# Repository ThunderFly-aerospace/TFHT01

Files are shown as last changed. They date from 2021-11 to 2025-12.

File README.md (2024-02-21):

# TFHT01 - UAV Humidity and Temperature Sensor



The TFHT01 hygrometer sensor offers flexible integration options. It can be directly connected to a Pixhawk autopilot with PX4 firmware, or it can be used as a sensor for the [TF-ATMON monitoring system](https://www.thunderfly.cz/tf-atmon.html).

Sensors mounted on UAVs can be used for a variety of purposes. TFHT01 can measure air temperature and humidity, which can be used for meteorological purposes to estimate whether icing may form on aerodynamic surfaces. It could also be used to determine if the flight is conducted within the operating range of the drone. Another use can be to measure the temperature of selected UAV components, for example, the temperature of batteries, ESC, motor, or some bearings. 

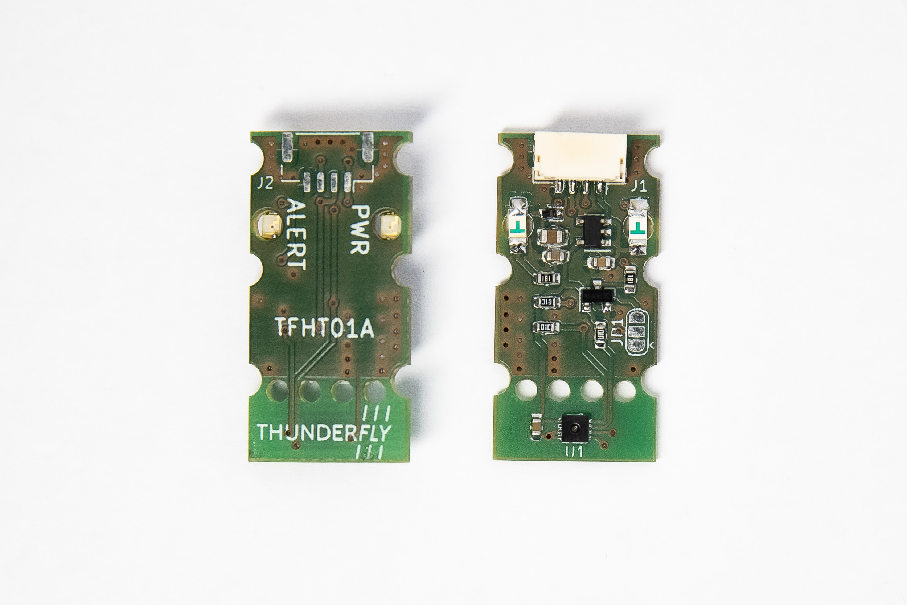
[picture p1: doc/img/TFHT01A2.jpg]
TFHT01A top view


## Where to get it?

The TFHT01 is commercially available from [ThunderFly s.r.o.](https://www.thunderfly.cz/). For a commercial quotation or support, contact us by email at sale@thunderfly.cz or shop at [Tindie store](https://www.tindie.com/products/thunderfly/tfht01-aerial-hygrometer-and-thermometer/).

## Parameters

| Parameter | Value | Description |
|---|---|---|
| Sensing element | [SHT35](https://sensirion.com/media/documents/213E6A3B/63A5A569/Datasheet_SHT3x_DIS.pdf) | Other possible sensors are SHT30 or SHT31 |
| Typical accuracy | 1.5 %RH and 0.1 °C | |
| Repeatability | 0.15 %RH , 0.08 °C | The stated repeatability is 3 times the standard deviation (3σ) of multiple consecutive measurements at constant ambient conditions. |
| Operating temperature range| 0 °C - +65 °C | Sensor physically measures in range -40°C to +120°C with reduced accuracy |
| Operating humidity range| 0-100 % | At humidity above 80% the performance of the sensor could be degraded in case of prolonged periods |
| I2C connector | 4-pin JST-GH | The second connector could be installed on the opposite side |
| I2C address | 0x44 default | By switching of JP1 is possible change address to 0x45 |
| Storage temperature range| -20 °C - +40 °C |  |
| Operational input voltage | 3.6 - 5.4V | Overvoltage internally protected by zener diode |
| Mass | 2 g | PCB without cabling |
| Dimensions | 30 x 15 x 6.5 mm |  PCB |
| Weather resistance | IP40 | External connectors fully occupied. The sensor itself could be protected by IP67 according the [sensirion datasheet](https://sensirion.com/media/documents/9D103E42/61641F0F/Sensirion_Humidity_Sensors_SHT3x_Datasheet_Filter_Membrane.pdf) |

## Applications

### Atmospheric sounding

The TFHT01 sensor could be used for [direct atmospheric sounding](https://en.wikipedia.org/wiki/Atmospheric_sounding). Here is an example of measured data taken by [TF-G2 autogyro](https://www.thunderfly.cz/tf-g2.html).

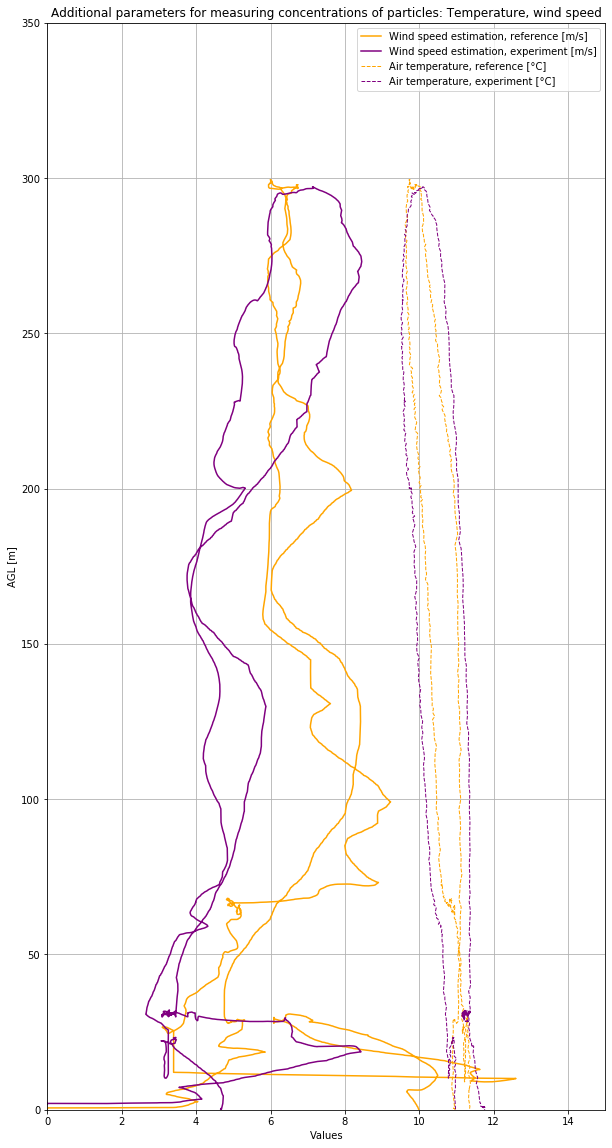
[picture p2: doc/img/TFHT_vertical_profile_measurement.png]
TFHT01A atmospheric profiling


## Schematics

Schematics

## Usage in PX4 autopilot firmware

The PX4 autopilot firmware supports the sensor. Multiple sensors can be connected to one autopilot. The measured data are immediately sent to the ground station and they are also logged in the onboard ulog file. Sensor support can be enabled by setting the [SENS_EN_SHT3X](http://docs.px4.io/master/en/advanced_config/parameter_reference.html#SENS_EN_SHT3X) parameter to 1.

### Driver Commands Examples

CLI usage example:

    sht3x start -X

Start the sensor driver on the external bus

    sht3x status

Print driver status

    sht3x values

Print the last measured values

    sht3x reset

Reinitialize senzor, reset flags

### PX4 Driver Usage

```
sht3x <command> [arguments...]
 Commands:
   start
     [-I]        Internal I2C bus(es)
     [-X]        External I2C bus(es)
     [-b <val>]  board-specific bus (default=all) (external SPI: n-th bus
                 (default=1))
     [-f <val>]  bus frequency in kHz
     [-q]        quiet startup (no message if no device found)
     [-a <val>]  I2C address
                 default: 68
     [-k]        If initialization (probing) fails, keep retrying periodically

   stop

   status        print status info

   values        Print actual data

   reset         Reinitialize sensor
```

## Usage in Ardupilot firmware

In the Ardupilot firmware, the corresponding sht3x driver for TFHT01 is currently missing. The contributions are welcomed. 

## Resources

  * [ThunderFly TFHT01 documentation page](https://docs.thunderfly.cz/avionics/TFHT01/)
  * [Store](https://www.tindie.com/products/26354/)
  * [Contact details](https://www.thunderfly.cz/contact-us.html)

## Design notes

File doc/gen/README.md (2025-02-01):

# PCB

Board size: 30.0x15.0 mm (1.18x0.59 inches)

- This is the size of the rectangle that contains the board
- Thickness: 0.89 mm (35 mils)
- Material: FR4
- Finish: HAL lead-free
- Layers: 2
- Copper thickness: 35 µm

Solder mask: TOP / BOTTOM

- Color: Green

Silk screen: TOP / BOTTOM

- Color: White

Stackup:

| Name | Type | Color | Thickness [µm]| Material | Er | Loss tan |
|---|---|---|---|---|---|---|
| F.SilkS | Top Silk Screen | | | | | |
| F.Mask | Top Solder Mask | Green | 10 | | | |
| F.Cu | copper | | 35 | | | |
| dielectric 1 | core | | 800 | FR4 | 4.5 | 0.020 |
| B.Cu | copper | | 35 | | | |
| B.Mask | Bottom Solder Mask | Green | 10 | | | |
| B.SilkS | Bottom Silk Screen | | | | | |

# Important sizes

Clearance: 0.2 mm (8 mils)

Track width: 0.3 mm (12 mils)

- By design rules: 0.15 mm (6 mils)

Drill: 0.5 mm (20 mils)

- Vias: 0.5 mm (20 mils) [Design: 0.4 mm (16 mils)]
- Pads: 1.0 mm (39 mils)
- The above values are real drill sizes, they add 0.1 mm (4 mils) to plated holes (PTH)

Via: 0.8/0.4 mm (31/16 mils)

- By design rules: 0.4/0.3 mm (16/12 mils)
- Micro via: yes [0.2/0.1 mm (8/4 mils)]
- Buried/blind via: yes
- Total: 36 (thru: 36 buried/blind: 0 micro: 0)

Outer Annular Ring: 0.15 mm (6 mils)

- By design rules: N/A mm (N/A mils)

Eurocircuits class: 4B
- Using min drill 0.5 mm for an OAR of 0.15 mm

# General stats

Components count: (SMD/THT)

- Top: 1/6 (SMD + THT)
- Bottom: 16/1 (SMD + THT)

Defined tracks:

- 0.3 mm (12 mils)
- 0.4 mm (16 mils)
- 0.5 mm (20 mils)
- 1.0 mm (39 mils)

Used tracks:

- 0.3 mm (12 mils) (54) defined: yes
- 0.4 mm (16 mils) (111) defined: yes

Defined vias:

Used vias:

- 0.8/0.4 mm (31/16 mils) (Count: 36, Aspect: 1.1 A) defined: no

Holes (excluding vias):

- 1.0 mm (39 mils) (12)
- 3.0 mm (118 mils) (6)

Oval holes:

Drill tools (including vias and computing adjusts and rounding):

- 0.5 mm (20 mils) (36)
- 1.0 mm (39 mils) (12)
- 3.0 mm (118 mils) (6)

Solder paste stats:

Using a paste with 87.75 % alloy, that has an specific gravity for the alloy of 7.4 g/cm³
and 1.0 g/cm³ for the flux. This paste has an specific gravity of  4.15 g/cm³.

The stencil thickness is  0.12 mm.

| Side | Pads with paste | Area [mm²] | Paste [g] |
|---|---|---|---|
| Top | 6 | 9.28 | 0.05 |
| Bottom | 47 | 40.69 | 0.20 |
| Total  | 53 | 49.97 | 0.25 |

Note: this is just an approximation to the theoretical value. Margins of the solder mask and waste aren't computed.

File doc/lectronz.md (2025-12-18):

The TFHT01 hygrometer sensor offers flexible integration options, including direct connection to a Pixhawk autopilot with PX4 firmware, or utilization as a sensor for the [TF-ATMON monitoring system](https://www.thunderfly.cz/tf-atmon.html). 

Once mounted on a UAV, the sensor provides valuable data for various applications. Its ability to measure atmospheric temperature and humidity can help estimate that icing may form on aerodynamic surfaces or determine if the drone is operating within the recommended range. Furthermore, the sensor can also be utilized to measure the temperature of specific UAV components such as batteries, ESCs, motors, or bearings, identifying potential issues before they escalate and supporting proactive maintenance and repairs.

Choose the TFHT01 hygrometer sensor for unparalleled flexibility, precision, and versatility in data collection. Whether you require temperature and humidity data for agricultural or industrial equipment monitoring or need to monitor drone component temperatures for optimal performance, the TFHT01 has you covered.

### What is it?

TFHT01 is a hygrometer and thermometer with an I2C interface for use on drones as an onboard weather station. Relative humidity and temperature are quantities that can affect both the flight characteristics of the drone and the execution of aerial works. At certain temperatures and relative humidity, icing can form on the lifting surfaces, worsening its flight characteristics or even causing a crash. Meteorological conditions can affect the payload as well - they can cause e.g. fogging on camera lenses, etc. It is therefore important to know about the presence of these phenomena during the flight.

| Parameter | Value | Description |
|---|---|---|
| Sensing element | [SHT35](https://sensirion.com/media/documents/213E6A3B/63A5A569/Datasheet_SHT3x_DIS.pdf) | Other possible sensors SHT30, SHT31 |
| Typical accuracy | 1.5 %RH and 0.1 °C | |
| Repeatability | 0.15 %RH , 0.08 °C | The stated repeatability is 3 times the standard deviation (3σ) of multiple consecutive measurements at constant ambient conditions. |
| Operating temperature range| 0 °C - +65 °C | Sensor physically measures in range -40°C to +120°C with reduced accuracy |
| Operating humidity range| 0-100 % | At humidity above 80% the performance of the sensor could be degraded in case of prolonged periods |
| I2C connector | 4-pin JST-GH | The second connector could be installed on the opposite side |
| I2C address | 0x44 default | By switching of JP1 is possible change address to 0x45 |
| Storage temperature range| -20 °C - +40 °C |  |
| Operational input voltage | 3.6 - 5.4V | Overvoltage internally protected by zener diode |
| Mass | 2 g | PCB without cabling |
| Dimensions | 30 x 15 x 6.5 mm |  PCB |
| Weather resistance | IP40 |  |

### How could be used 
We developed the TFHT01 because we needed to know the temperature and humidity of the environment in which we operate our drones. At that time no such sensor was commercially available on the market.

### Special features
The sensor is unique because it is ready to be immediately used on drones. It complies with the widely used dronecode standards and it is equipped with indicator diodes that help with quick diagnostics of the status of the sensor and its operating status.

Furthermore, the sensor has a specific construction that makes it possible to place it in the outdoor environment easily. Alternatively, the sensor can be used as a diagnostics probe for drone avionics’ (e.g. engines, regulators, or batteries).

### Compatibility with autopilots

Our sensor is fully compatible with the dronecode standards. In terms of software, the sensor is supported by [PX4 autopilot](https://px4.io/). The driver is programmed as a so-called multi-instance. Thanks to this it is possible to connect multiple TFHT01 sensors to the autopilot (they can be located in different parts of the drone or measure data from different drone’s components). This should be done concerning I2C bus properties, e.g. requirement of [different addresses for each device on the bus](https://lectronz.com/products/1063).

### Use with PX4

Complete settings and driver options under PX4 can be found in the [documentation](https://docs.px4.io/main/en/modules/modules_driver.html#sht3x).

To start the driver automatically it is only necessary to connect the sensor to any I2C port and set the `SENS_EN_SHT3x` parameter to 1 (enabled). The sensor should initialize during the next start. The prerequisite is to use the PX4 firmware version newer than 2022/03.

You can check that the driver is running and the sensor is initialized, after turning the driver on, the LED ‘ALERT’ is off.

Data is logged locally in the drone’s onboard avionics and is sent via Mavlink to the ground station. The values can be viewed in real-time using control software e.g. [QGC](http://qgroundcontrol.com/).

### Another usage
The sensor can be used outside of drones and PX4 devices as well. The I2C interface is the 4-pin JST-GH connector. The sensor board also contains I2C pull-ups and that’s why the sensor can be connected to e.g. Arduino or other single-board computers and they can be used to read the data from the sensor. The suggested supply voltage is 5V.

### What’s included?

- 1x TFHT01 with [SHT35 sensor with PTFE membrane](https://sensirion.com/media/documents/9D103E42/61641F0F/Sensirion_Humidity_Sensors_SHT3x_Datasheet_Filter_Membrane.pdf)
- Optionally 1x JST-GH 4-pin I2C cable in accordance to [cable style](https://docs.px4.io/main/en/assembly/cable_wiring.html#i2c-cables)

# Product changelog
The product is gradually evolving and improving based on user requirements. Currently (as of 11/2024), the TFHT01B revision is being shipped. In the development process, we keep backward compatibility, for example by keeping the same form factor or communication interface. The complete list of changes is in [releases](https://github.com/ThunderFly-aerospace/TFHT01/releases).

#### TFHT01B (from 11/2024)
Introduced the use of membrane-covered sensors, and 3D printed sensor housing to enhance environmental protection.

#### TFHT01B (from 10/2023)
PCBs are covered by shrink tubing to increase protection. 

#### TFHT01B (from 05/2022)
PCB Thickness decreased to 0.8mm. 

#### TFHT01A (from 09/2021)
Bare PCB version with 1.6mm thickness

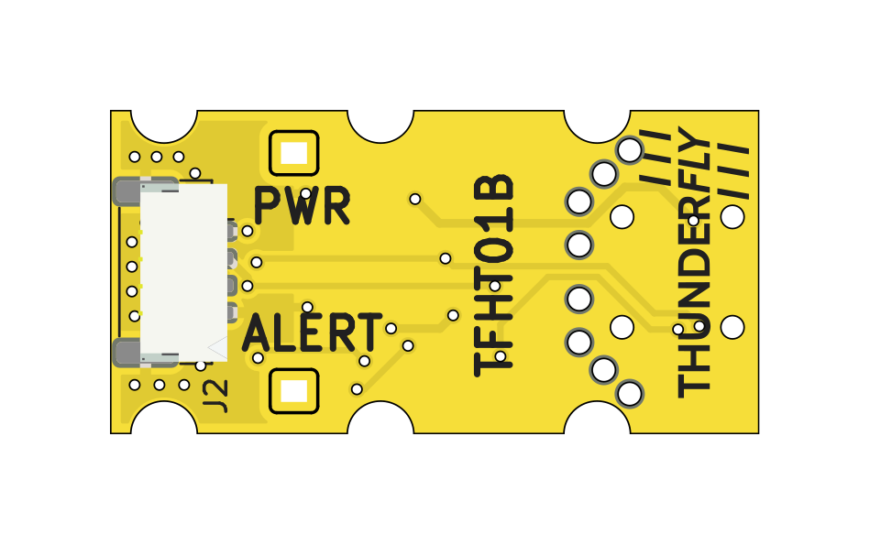
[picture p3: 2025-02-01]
doc/gen/img/TFHT01-top.png

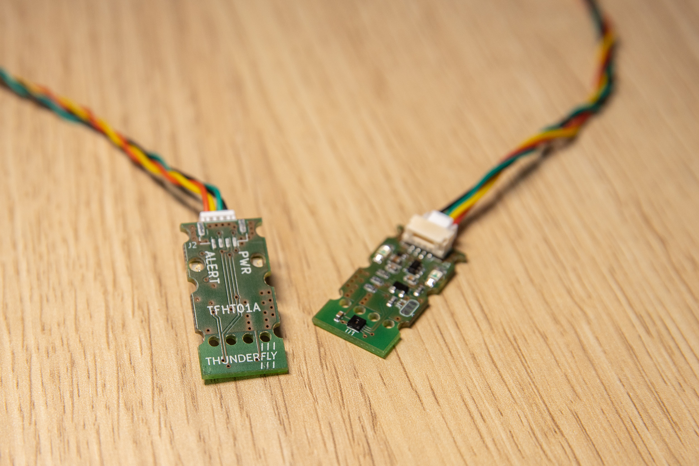
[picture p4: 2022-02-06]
doc/img/TFHT01A1.jpg

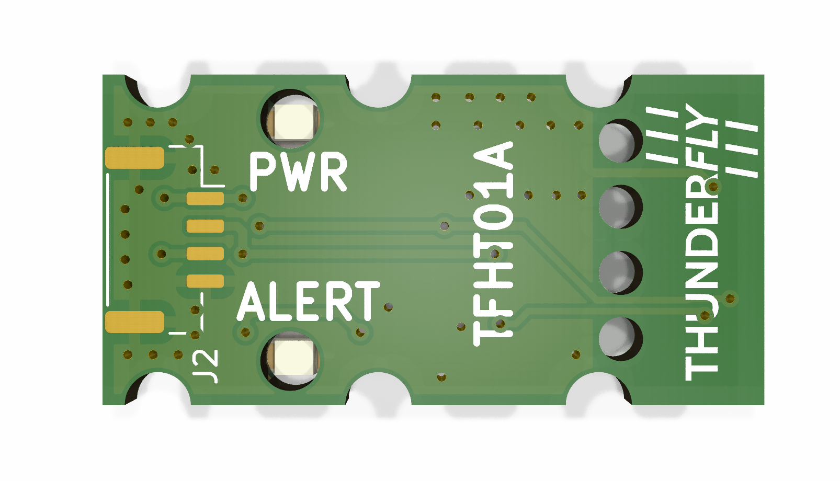
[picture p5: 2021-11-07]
doc/img/TFHT01A_top.png

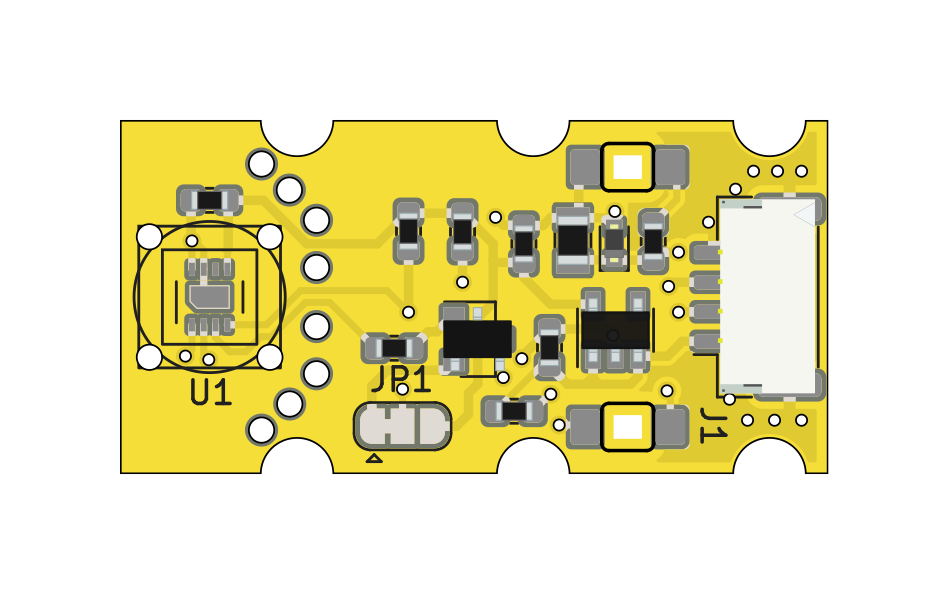
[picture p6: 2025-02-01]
doc/gen/img/TFHT01-bottom.png

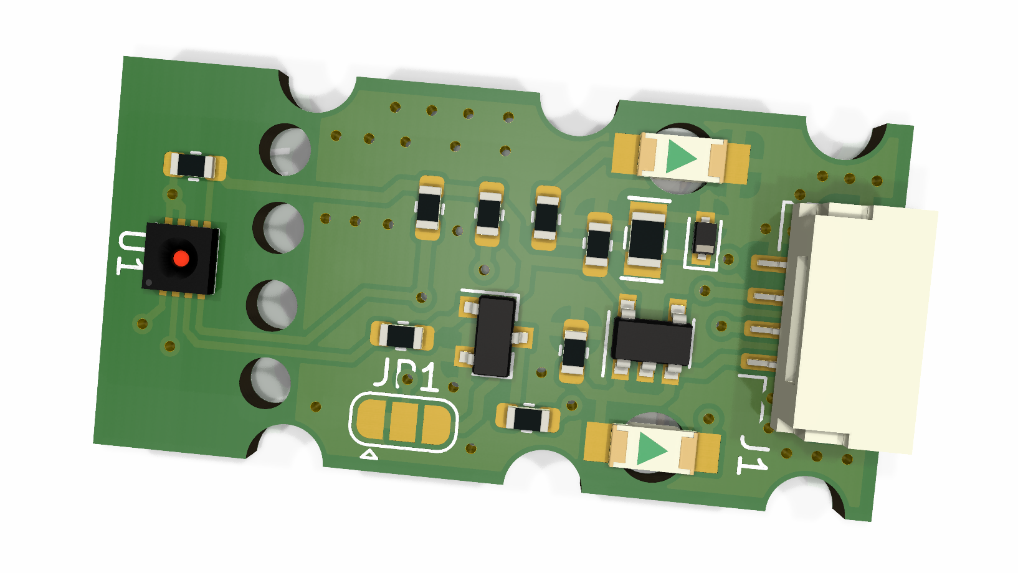
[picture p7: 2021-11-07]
doc/img/TFHT01A_bot.png

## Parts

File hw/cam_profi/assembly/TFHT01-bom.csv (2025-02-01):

Component | Description | Part | References | Value | Footprint | Quantity Per PCB | Datasheet | ust_id
1 | Unpolarized capacitor | C | C4C5 | 100nF | SMD-0603 | 2 | ~ | 5c70984812875079b91f8bf2
2 | Unpolarized capacitor | C | C1 | 1uF | SMD-0603 | 1 | ~ | 5c70984812875079b91f8bc2
3 | Unpolarized capacitor | C | C3 | 10uF | SMD-0805 | 1 | ~ | 5c70984812875079b91f8bbd
4 |  | D_ZENER | D1 | BZX585-B5V6.115 | D_SOD-523 | 1 |  | 60879d38128750769ee58e48
5 | Light emitting diode | LED | D2 | LED GREEN | LED_1206_mill | 1 | ~ | 5c70984412875079b91f8895
6 | Light emitting diode | LED | D3 | LED RED | LED_1206_mill | 1 | ~ | 5c70984412875079b91f8896
7 |  | SM04B-GHS-TB | J1J2 | SM04B-GHS-TB | JST_GH_SM04B-GHS-TB_1x04-1MP_P1.25mm_Horizontal | 2 |  | 5c86273d1287500b4e0280be
8 |  | CAP-SF2 | M7 | CAP-SF2 | CAP-SF2 | 1
9 | 0.8A Ic, 45V Vce, NPN Transistor, SOT-23 | BC817 | Q1 | BC817 | SOT-23 | 1 | http://www.fairchildsemi.com/ds/BC/BC817.pdf | 5c70984712875079b91f8aec
10 | Resistor | R | R1R4 | 180R | SMD-0603 | 2 | ~ | 5c70984512875079b91f8957
11 | Resistor | R | R2R3R10 | 10k | SMD-0603 | 3 | ~ | 5c70984512875079b91f8962
12 | 300mA Low-dropout Voltage Regulator, Vout 3.3V, Vin up to 5.5V, SOT-23 | MIC5504-3.3YM5 | U3 | MIC5504-3.3YM5 | SOT-23-5 | 1 | http://ww1.microchip.com/downloads/en/DeviceDoc/MIC550X.pdf | 5c7255e81287500b4e112ea2
13 | I²C humidity and temperature sensor, ±1.5%RH, ±0.2°C, AEQ-100, DFN-8 | SHT35A-DIS | U1 | SHT35A-DIS | Sensirion_DFN-8-1EP_2.5x2.5mm_P0.5mm_EP1.1x1.7mm | 1 | https://www.sensirion.com/fileadmin/user_upload/customers/sensirion/Dokumente/2_Humidity_Sensors/Datasheets/Sensirion_Humidity_Sensors_SHT3xA_Datasheet.pdf | 65103c42462c6d9e72054b8e

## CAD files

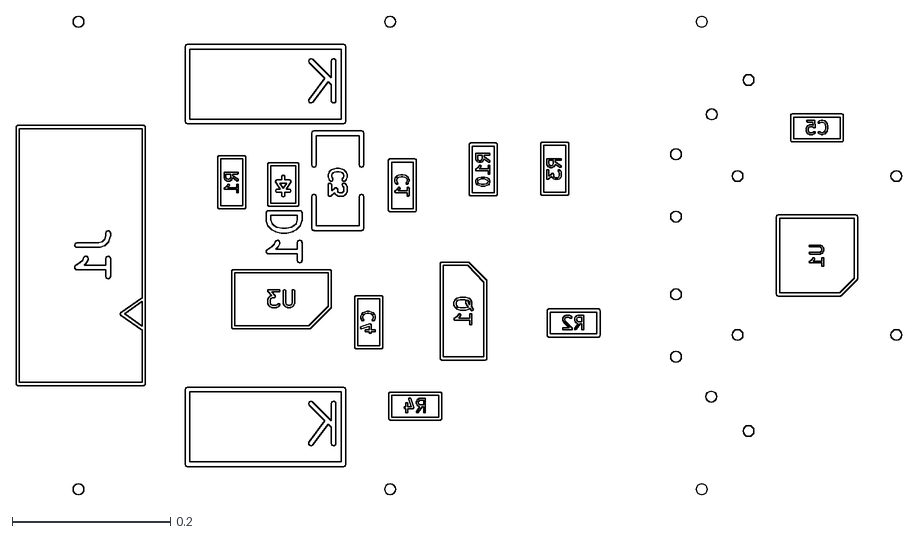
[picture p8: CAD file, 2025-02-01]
doc/gen/dxf/TFHT01-B_Fab.dxf
1.12 x 0.604

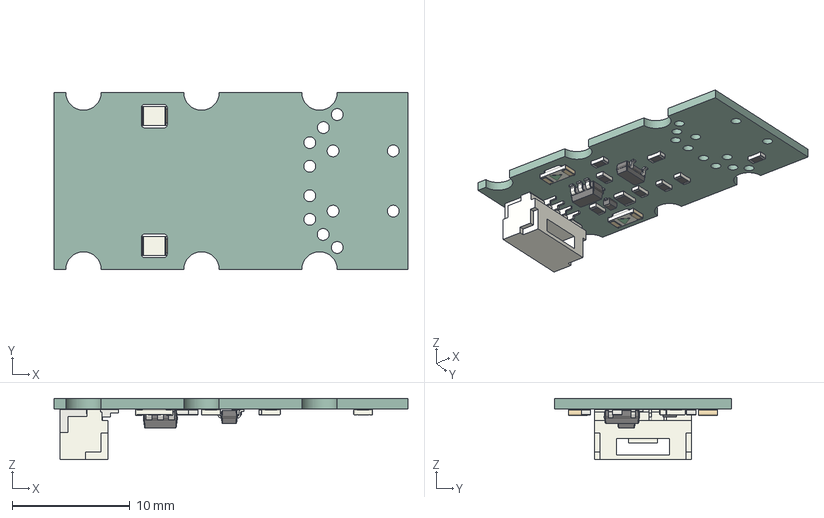
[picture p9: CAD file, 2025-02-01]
doc/gen/TFHT01.step
30.0 x 15.0 x 5.18 mm
LED_1206_3216Metric x 2
R_0603_1608Metric x 8
D_SOD_523
JST_SM04B_GHS_TB
SOT_23
R_0805_2012Metric
SOT_23_5
kibot_k8tr6jyj_PCB

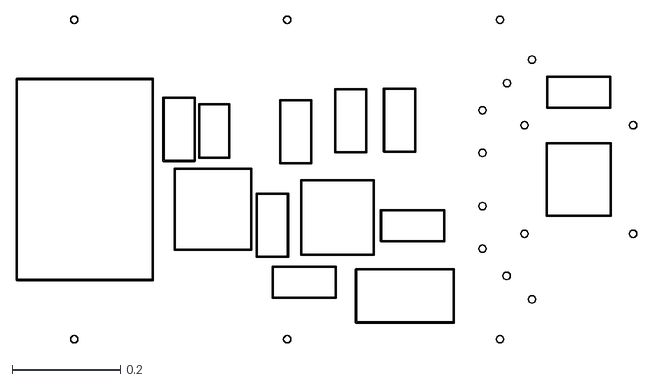
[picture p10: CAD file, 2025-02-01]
doc/gen/dxf/TFHT01-B_Courtyard.dxf
1.15 x 0.604

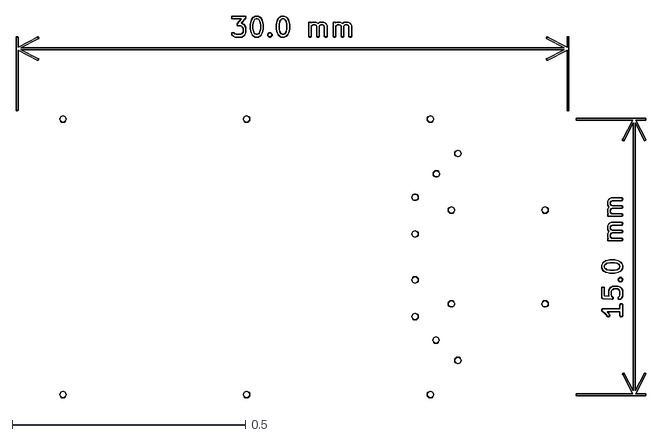
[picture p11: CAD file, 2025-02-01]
doc/gen/dxf/TFHT01-User_Drawings.dxf
1.35 x 0.818

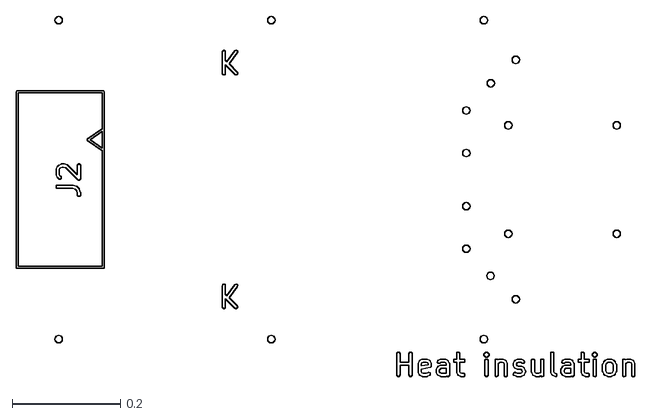
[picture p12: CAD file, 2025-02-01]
doc/gen/dxf/TFHT01-F_Fab.dxf
1.15 x 0.667

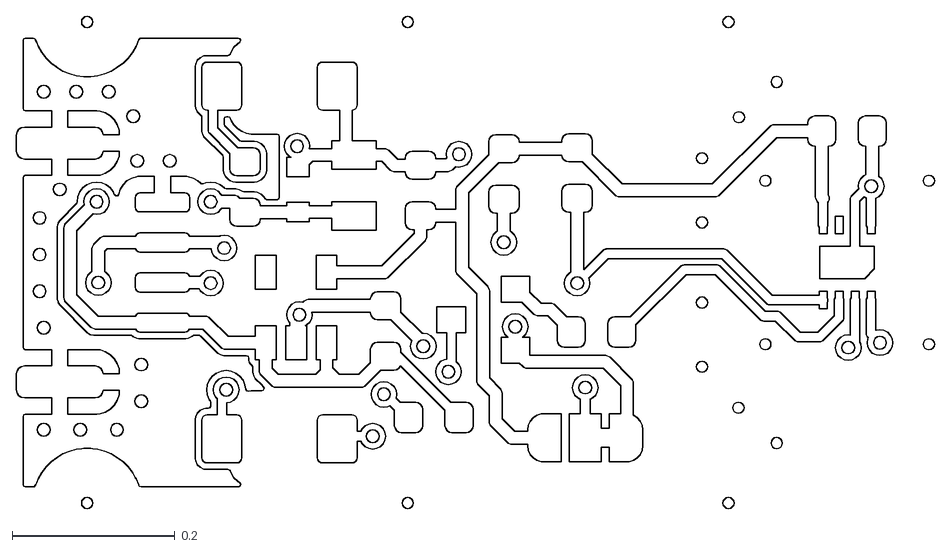
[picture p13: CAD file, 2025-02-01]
doc/gen/dxf/TFHT01-B_Cu.dxf
1.13 x 0.604

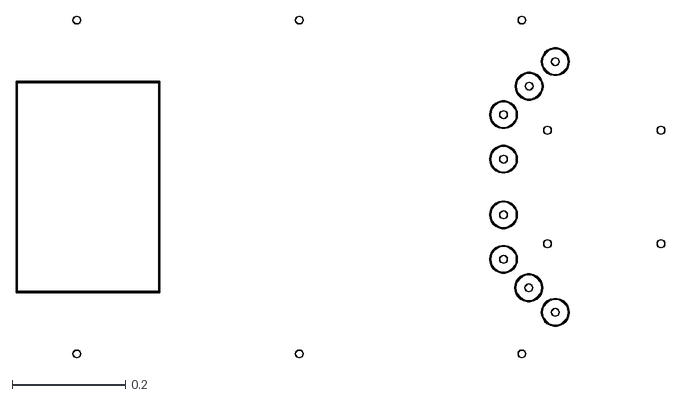
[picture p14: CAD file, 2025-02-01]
doc/gen/dxf/TFHT01-F_Courtyard.dxf
1.15 x 0.604

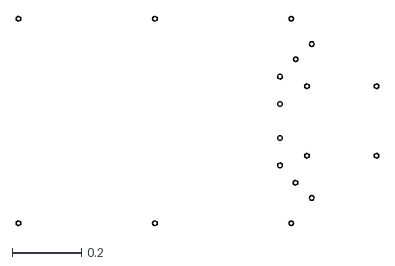
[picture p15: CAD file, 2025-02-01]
doc/gen/dxf/TFHT01-Margin.dxf
1.05 x 0.604

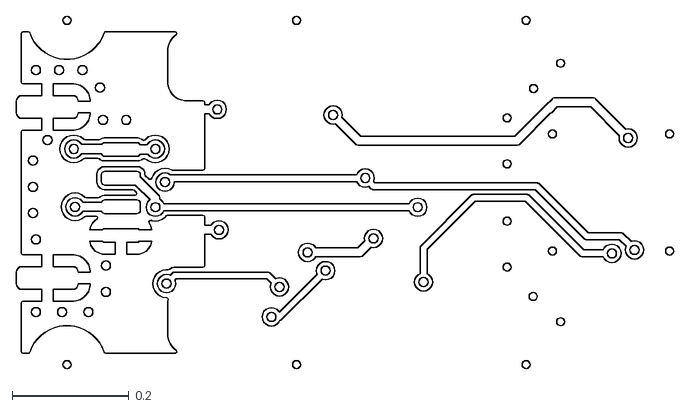
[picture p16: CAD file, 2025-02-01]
doc/gen/dxf/TFHT01-F_Cu.dxf
1.13 x 0.604

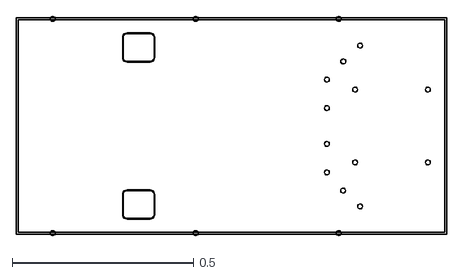
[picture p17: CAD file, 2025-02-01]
doc/gen/dxf/TFHT01-Edge_Cuts.dxf
1.19 x 0.604

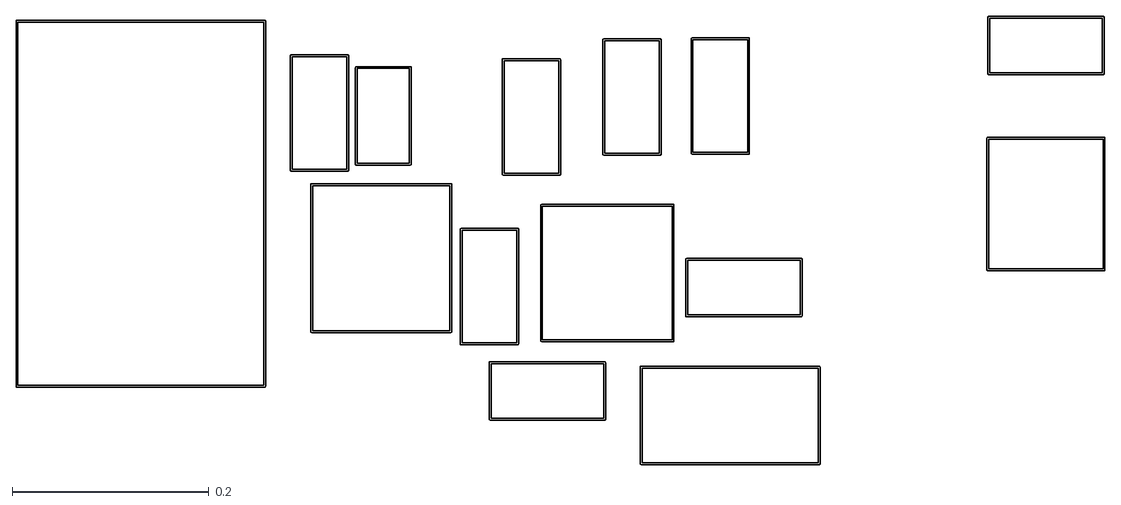
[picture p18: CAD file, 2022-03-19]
doc/gen/dxf/TFHT01B-B_Courtyard.dxf
1.11 x 0.456

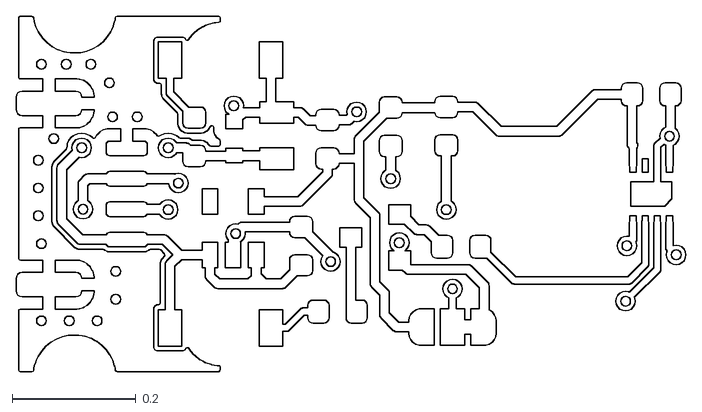
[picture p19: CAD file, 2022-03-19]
doc/gen/dxf/TFHT01B-B_Cu.dxf
1.08 x 0.575

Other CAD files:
doc/gen/dxf/TFHT01-B_Mask.dxf
doc/gen/dxf/TFHT01-B_Paste.dxf
doc/gen/dxf/TFHT01-B_Silkscreen.dxf
doc/gen/dxf/TFHT01-F_Mask.dxf
doc/gen/dxf/TFHT01-F_Paste.dxf
doc/gen/dxf/TFHT01-F_Silkscreen.dxf
doc/gen/dxf/TFHT01B-B_Mask.dxf
doc/gen/dxf/TFHT01B-B_Silkscreen.dxf
doc/gen/dxf/TFHT01B-F_Silkscreen.dxf

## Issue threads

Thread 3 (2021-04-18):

LED label

ChroustJan, 2021-04-18:
@kaklik jaký by měl být text popisků LED?

roman-dvorak, 2021-04-18:
navrhuji:
* PWR
* ALERT

kaklik, 2021-04-18:
Jo Romanův návrh PWR je lepší než můj návrh ON, zde. https://github.com/ThunderFly-aerospace/TFI2CEXT01/issues/4#issuecomment-821993203. Navrhuju to sjednotit na PWR.

ChroustJan, 2021-04-23:
Finální popisek:
PWR
ALERT

Closed 2021-04-23.

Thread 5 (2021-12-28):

Sensor membrane

kaklik, 2021-12-28:
Na další snímače by to chtělo osadit variantu senzorů s [krycím filtrem](https://www.sensirion.com/fileadmin/user_upload/customers/sensirion/Dokumente/2_Humidity_Sensors/Datasheets/Sensirion_Humidity_Sensors_SHT3x_Datasheet_Filter_Membran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), který by měl zabránit znečištění senzoru ve venkovním prostředí.

roman-dvorak, 2022-01-04:
Na telefonu 4. 1. 2022 bylo dohodnuto, že se upraví PCB tak, aby podporoval montáž čepičky [CAP-SF2](https://www.sensirion.com/en/environmental-sensors/humidity-sensors/filter-cap-sf2/), knerá má být schopná zvýšit odolnost senzoru na IP57 (mělo by to být možné ponořit do vody).

Pod čepičku se bude standartně osazovat SHT31.
Jestli to bude varianta s kaptonovou páskou, tak to je na Honzovi. Tak, aby nemohlo při osazování (resp. mytí) dojít k poškození senzoru.

kaklik, 2022-03-12:
Možná že by bylo docela dobré, kdyby TFHT01 bylo vyrobeno na tenčím FR4.  Jednak by se tím ušetřila nějaká hmotnost a potom by filtrační čepička lépe pasovala do otvorů.

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

kaklik, 2022-03-12:
Jsem to překreslil

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

ChroustJan, 2023-08-04:
PCB bude mít 0,8mm

kaklik, 2024-03-17:
Lepší by bylo nahradit čepičku vhodně konstruovanou krabičkou. #10

Closed 2024-03-17.

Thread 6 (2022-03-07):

TFHT01 QGCS configuration

Murali-IsPagro, 2022-03-07:
I am need to measure temperature at 4 different points. how to configure in QGCS if i am connecting the sensor in pixhawk ? Any link for configuration details or setup details?

roman-dvorak, 2022-03-07:
Hello, multiple TFHT01 sensors can be connected to an autopilot with PX4 firmware. The firmware produces a multi-instance uORB message and logs it.

Two sensors can be connected to one bus (with changed address). If you need to connect more sensors, this can be solved by our I2C address translator [TFI2CADT01](https://github.com/ThunderFly-aerospace/TFI2CADT01). We can offer it as a complete solution.

The message is also sent to MAVLINK network. It can be displayed in the QGC [Mavlink inspector](https://docs.qgroundcontrol.com/master/en/analyze_view/mavlink_inspector.html) tool.

What type of autopilot you want to use? Sensor support can be enabled by setting the `[SENS_EN_SHT3X](http://docs.px4.io/master/en/advanced_config/parameter_reference.html#SENS_EN_SHT3X)` parameter to 1.

Murali-IsPagro, 2022-03-08:
I will be using px4 firmware, Pixhawk 2.4.8. You gave me an answer . "Sensor support can be enabled by setting the [SENS_EN_SHT3X](http://docs.px4.io/master/en/advanced_config/parameter_reference.html#SENS_EN_SHT3X) parameter to 1." This is what i was looking for.

Thank you

Closed 2022-03-08.

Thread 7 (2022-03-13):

Nadměrné zahřívání senzoru

roman-dvorak, 2022-03-13:
U dvou TFHT01 senzorů bylo pozorované nadměrné zahřívání.

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

V datasheetu je tato poznámka. Senzor nebyl při měření plně zinicializovaný (neměl vyresetovaný alert registr) a díky tomu mu svítila ALERT LEDka.
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

Podle schéma je tam osazený pouze 100R odpor
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

Což znamená, že senzor je mnohonásobně proudově přetěžován. Opakoavaně jsem kontroloval, že interní vyhřívání senzoru je vypnuté.

Pocitově se ale nejvíce zahřívá střed PCB, kde je umístěný tranzistor a LDO (které díky tomuto incidentu jsou také zbytečně moc vytěžované)

Již při předchozích měření na vírníku bylo pozorováno, že TFHT má o něco vyšší teplotu než teploměr v airspeed senzoru (i když byly jen kus od sebe). Bylo to o jednotky C a nebyla tomu věnována pozornost.

kaklik, 2022-03-13:
Přepočítal jsem parametry toho zapojení.  A za předpokladu, že je tam osazena [tato červená LED](https://www.tme.eu/Document/f2476645d882a001b970b9780aa7dc45/FYLS-1206URC.pdf). Tak současné zapojení umožňuje (5,4-2.1)/180=0,018 A.  Použitý [tranzistor BC817](https://assets.nexperia.com/documents/data-sheet/BC817_SER.pdf), má zesílení minimálně 100.  Tudíž proud do báze musí být v nejhorším případě 100x menší.  To je 0,18 mA.    Při úbytku BE 0,5V by takový proud odpovídal rezistoru v bázi tranzistoru 15k2.  Taková hodnota rezistoru ale není v zapojení nikde použita.
Proto dává větší smysl použít existující hodnotu rezistoru 10k.  Proud do báze tak sice bude mírně vyšší (0,28mA) ale stále řádově menší než současných 28mA.

Ve verzi TFHT01B jsem hodnotu rezistoru opravil.

roman-dvorak, 2022-03-14:
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

Vypnutí LEDky opravdu toto sebezahřívání dost zmenšilo. I tak ale senzor měří o dost (cca 3C) vyšší teplotu než SEN54. Je to vidět na grafu. Všechny senzory jsou umístěné vedle sebe. A i přes nějaké teplotní změny (větrání v pokoji) je jejich offset konstantní. Je to velmi podobná situace jako na vírníku. Viz následující graf:

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
Zde je ale rozdíl, že senzor byl ochlazován a temperován docela velkým množstvím vzduchu protékajícím okolo.

Měření bylo provedeno s nejmenší možnou měřící frekvencí kontinuelního měření (tj. 0.5 Hz). Aby nedocházlo k sebezahřívání z tohoto důvodu.

roman-dvorak, 2022-03-17:
HYGRO01 - TFHT01A v původním osazení z první várky
HYGRO02 - TFDH01A s opravenou hodnotou odporu pro ALERT Ledku (ALERT ledka je zhasnutá)

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

HYGRO02 je včera osazený TFHT. V cca 9h (peak v grafu, ohřátý po pájení) jsem z něj odpájel LEDku. Modrý graf (HYGRO01) má LEDku power stále zapnutou. Je vidět, že po odpájení LEDky poklesla teplota na hodnotu měřenou v SEN54 senzoru.

Vypadá to, že 50mW vytvořené odporem před ledkou a ledkou samotnou zahřívá celý senzor o cca 2C. Senzor je umístěn venku, kde je okolo něj přirozené proudění vzduchu.

kaklik, 2022-03-17:
Navrhuju udělat dvě změny:

1. Snížit proud skrz LED indikující napájení použitím většího odporu
2. Udělat revizi PCB, která nebude obsahovat vylitou měď. Tím pádem bude omezen přenos tepla k senzoru.

kaklik, 2022-03-19:
Ještě jsem rezistor od LED nyní v revizi B přesunul blíže JST-GH konektoru, čímž se dostal dále od snímače.

kaklik, 2023-06-21:
Dalšího zlepšení lze zřejmě dosáhnout odebráním vylité mědi, aby byla snížena tepelná vodivost od rezistorů směrem ke snímači.

kaklik, 2023-07-30:
Zde je situace dobře viditelná na FIR snímku. Snímač, který je výše  má odpojenou LED indikující napájení. LED ALERT svítila jen chvíli, než se senzor inicializoval.
Na snímku je kromě jiného vidět i účinnost vrtaných otvorů.

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

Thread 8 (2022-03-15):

LED type

ChroustJan, 2022-03-15:
Ve verzi 01B bych navrhoval předělat LED do pouzdra 0603. Ty jsme nově začali používat u nových modulů. Potisk na PCB bude z obou stran.

kaklik, 2022-03-15:
Já myslím, že takové rozhodnutí hodně závisí na základním mechanickém uspořádání, které bude použité pro montáž na UAV.
 Reverzní montáž LED bych úplně univerzálně u TF modulů nerušil. Jen to u některých nedává tolik smysl.  (Původní plán uvažoval zejména s využitím pro čidla)

ChroustJan, 2022-03-15:
To neumím rozhodnout. Reverzní montáž je složitější. To vím.

kaklik, 2022-03-19:
> To neumím rozhodnout. Reverzní montáž je složitější. To vím.

V čem je reverzní montáž složitější, když se použijí LED pro reverzní montáž určené?

Já tady ve zrušení té reverzní montáže.  (a obecně u čidel) nevidím velký smysl.  Podle mě je v případě předpokládané montáže senzoru #10  dokonce výhodné, aby LED svítila hlavně na opačnou stranu než je čidlo.  Citlivá část čidla pak může být otočena směrem dolů a tím se v čidle nebude držet voda ani prach. Naopak LED budou z vrchní i spodní strany pravděpodobně snadno viditelné.

ChroustJan, 2022-03-21:
Je potřeba tedy vyřešit správnost footprint. Kvůli DRC se posunuli plošky. Je tedy potřeba přidávat větší množství pasty a někdy i ruční oprava. Dochází k přitažení LED k jedné straně a na druhé straně není kontakt vůbec.

kaklik, 2022-03-21:
Myslím že je chyba řešit chybovou hlášku DRC úpravou footprintu, pokud úprava způsobí technologické potíže.  (Smysl DRC je přesně opačný).
Navíc chybovou hlášku DRC je možné skrýt, čímž přestane generovat neprůchodný výsledek testu.

ChroustJan, 2022-03-21:
Navrhuji vyzkoušet pouzdro, které dal @roman-dvorak  do TFRPM01D. Zavádí příplatkové vnitřní frézování, ale mělo by to řešit problém s osazováním. Nevím zda @roman-dvorak  kontrolovat zda se do díry LED opravdu vejde.

ChroustJan, 2023-02-15:
Romanova změna nebyla dobrá. Udělal jsem jinou. Aktuálně se problém při osazování snížil na minimum.

kaklik, 2023-02-15:
> Romanova změna nebyla dobrá. Udělal jsem jinou. Aktuálně se problém při osazování snížil na minimum.

A skutečně to zavádí nějaký příplatek za vnitřní frézování, nebo to stojí stejně?

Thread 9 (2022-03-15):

Distance of conductive paths from drilled holes

ChroustJan, 2022-03-15:
Je potřeba si ohlídat vzdálenost vodivých cest od vrtaných otvorů. Přijdou mi dost blízko (cca 0,1mm):
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

Snažil jsem se najít nějakou informaci u výrobce, ale nenašel jsem. Jediné co tam mají je vzdálenost mědi od frézování a ta je definovaná jako 0,15mm. Tak bych považoval za rozumné nastavit aspoň tu. Ideálně klidně i větší.

kaklik, 2022-03-15:
Ok, opravíš to, nebo nastavíš to prosím rovnou v tom projektu?

Je tam ještě obdobný problém.. vzdálenosti děr pro CAP-SF2 o okrajů desky. To taktéž nevím zda je nyní správně.

kaklik, 2022-03-15:
> Pokud na tom budu pracovat tak to opravím.
>
> CAP-SF2 je takto špatně. Hrozí že tam bude drážkování a tam je dobré dodržet minimálně 0,5mm vzdálenost mědi od okraje a pak ještě rezervu, aby se to nevylamovalo.

CAP-SF2 ale žádnou měď nepoužívá.

ChroustJan, 2022-03-15:
Těch 0,5mm jsem myslel ve smyslu ochranného pásma pro drážkování. Navrhoval bych jako minimum pro vrtanou díru aspoň 2,5mm. Spíš možná i 3,5mm. Je potřeba brát ohled na nožičky CAP-SF2, že za něco musí držet:
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

kaklik, 2022-03-18:
> Těch 0,5mm jsem myslel ve smyslu ochranného pásma pro drážkování. Navrhoval bych jako minimum pro vrtanou díru aspoň 2,5mm. Spíš možná i 3,5mm. Je potřeba brát ohled na nožičky CAP-SF2, že za něco musí držet: 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

Aby tyhle packy měly ten smysl ke kterému jsou zamýšlené, tak by to PCB muselo mít přibližně poloviční tloušťku.

roman-dvorak, 2022-03-18:
A nešlo by mít pro packy z druhé strany vyvrtané zahloubení? Obdoba zahloubení pro válcovou hlavu šroubu (viz obrázek) Netuším, jak se to definuje ve výrobních datech, ale to by snad mělo jít domluvit s výrobcem.

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

Ale je fakt, že tenčí PCB bude mít menší tepelnou kapacitu, což je u tohoto senzoru docela žádoucí.

kaklik, 2022-03-19:
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

Tohle sice domluvit jde. (Dělá se to tak, že se pošle další vrstva z druhý strany, kde to má být s textovým popisem toho, jak to má být hluboko). Nicméně to bude téměř jistě za příplatek.
Raději bych tady byl pro variantu tenčího PCB, protože to má myslím smysl jak v ušetření hmotnosti, tak i v menší tepelné kapacitě.    Úplně ideální by zde bylo ridig-flex PCB, ale to je asi pro první produkční verzi takového senzoru asi zbytečný.

kaklik, 2023-07-30:
Tohle mi připadá vyřešené. Respektive další relevantní diskuse je spíš v #5

Closed 2023-07-30.

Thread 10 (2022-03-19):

Sensor mount options

kaklik, 2022-03-19:
Před produkcí by bylo potřeba navrhnout nějaký referenční způsob uchycení senzoru na UAV.  Takové uchycení by pak mohlo [snímat OAT](https://en.wikipedia.org/wiki/Outside_air_temperature).

Běžně takový senzor vypadá nějak takhle:

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
[zdroj](https://www.collinsaerospace.com/-/media/project/collinsaerospace/collinsaerospace-website/product-assets/files/commercial/flight-deck/surveillance/air-data-systems/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)

Obvykle to tak je aerodynamický profil ve kterém je dutina, která je spojená s vnějším prostředím otvory.  Taková konstrukce se používá pro nízké rychlosti, kde je zahřátí adiabatickou kompresí zanedbatelné.

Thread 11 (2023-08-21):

ALERT LED failure

kaklik, 2023-08-21:
Zjistil jsem, že na čidle vyndaném z meteoboxu, kde nesvítila ALERT LED. Bylo to tím, že byla vnitřně zkratovaná.
Zřejmě se jí přihodilo něco nepříjemného, pochybuji, že by byla vadná z výroby.

Řešení zřejmě souvisí jednak s tím, že by bylo vhodné layout upravit tak, aby zkratování nožičky LED (nejpravděpodobněji asi s GND) nemohlo LED zničit.  A taky je zřejmě potřeba nějak vyřešit zakrytování celého snímače #10

ChroustJan, 2023-09-24:
Prohodil jsem LED s R:
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

Closed 2023-11-09.

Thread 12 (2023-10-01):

EMI imunity

kaklik, 2023-10-01:
Nové provedení vedení cest, které na PCB je umožňuje cross talk mezi SDA a SCL vodiči, protože vedou přesně nad sebou.

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

Mnohem lepší by bylo, kdyby SDA vedlo nad Alert signálem. Net který slouží k výběru adresy by pak mohl vést mezi vedlejší dvojicí děr.

Toto současné řešení je neoptimální i z hlediska #7 protože koncentruje měděné cesty do jednoho místa, kde se budou hůře chladit okolním vzduchem.

Také úpravou na PCB vznikl tento ostrý úhel, který je navíc na signálovém vodiči, kde má potenciál vytvářet odrazy:

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

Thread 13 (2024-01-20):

Timestamp_sample overflow in recorded flight data log

kaklik, 2024-01-20:
There seems to be an issue with the TFHT driver where overflows timestamp_sample values.

![Uploading 79127f9d-4f6d-41fb-8419-fc9d285d032a.png…]()

kaklik, 2025-06-21:
That seems to be possibly fixed after merging [this pull-request](https://github.com/PX4/PX4-Autopilot/pull/24264).

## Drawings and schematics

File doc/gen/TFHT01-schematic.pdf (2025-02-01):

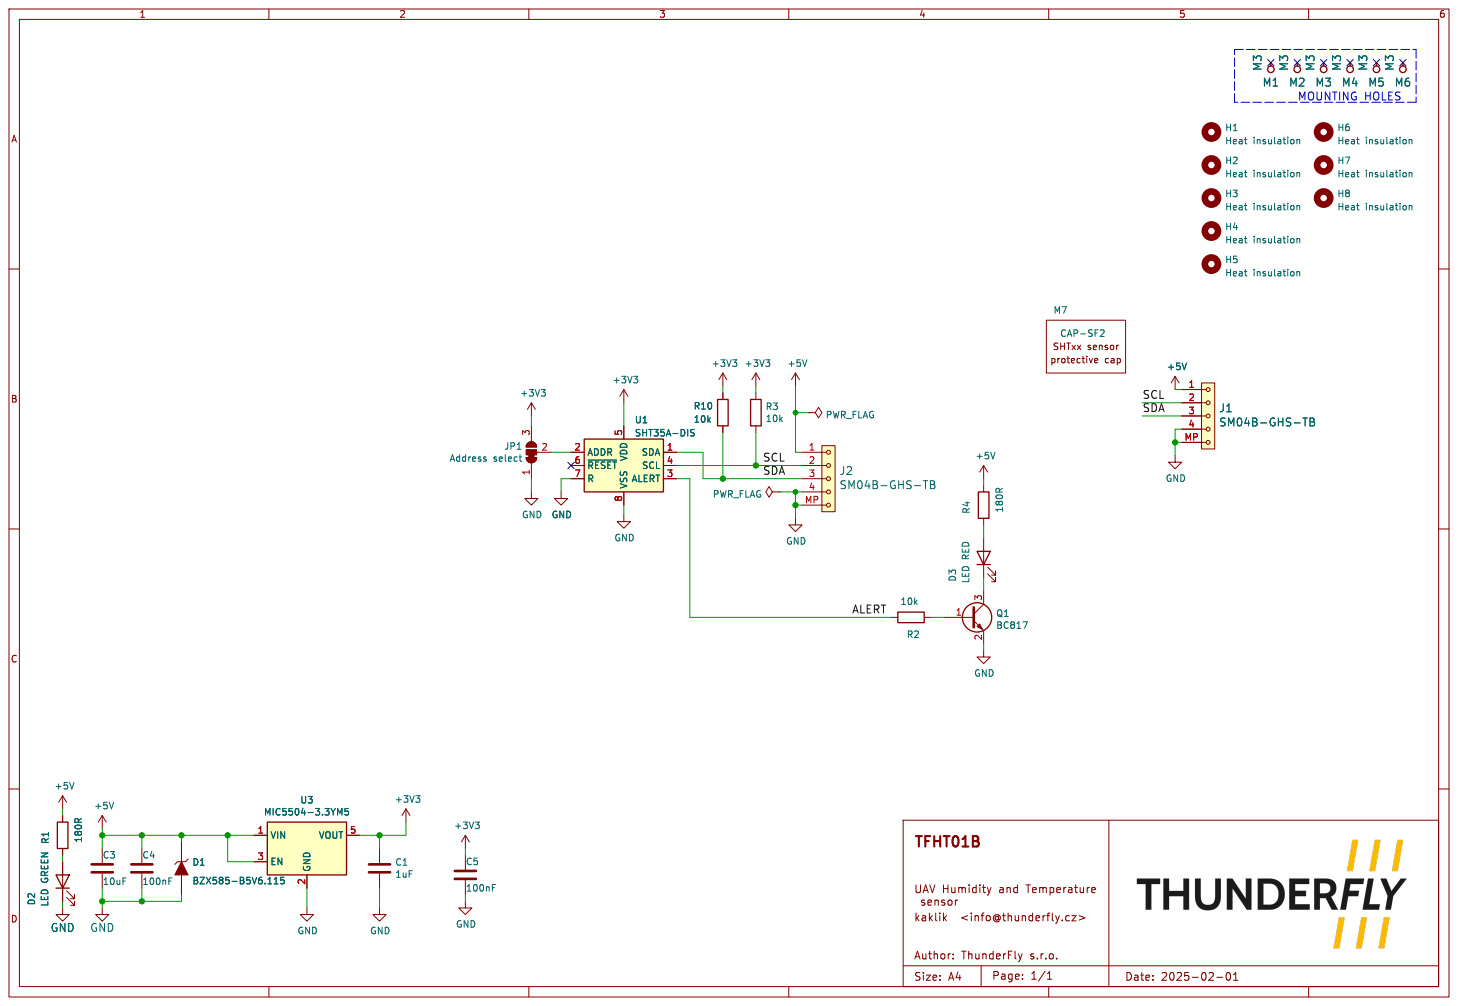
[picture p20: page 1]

M2 M3 H4 Heat insulation SCL ALERT SCL

H8 Heat insulation H7 Heat insulation H6 Heat insulation H2 Heat insulation GND

H5 Heat insulation H3 Heat insulation

2 EN 3 VOUT 5 U3 MIC5504-3.3YM5 GND GND

2 EN 3 VOUT 5 D1BZX585-B5V6.115 GND D2 LED GREEN

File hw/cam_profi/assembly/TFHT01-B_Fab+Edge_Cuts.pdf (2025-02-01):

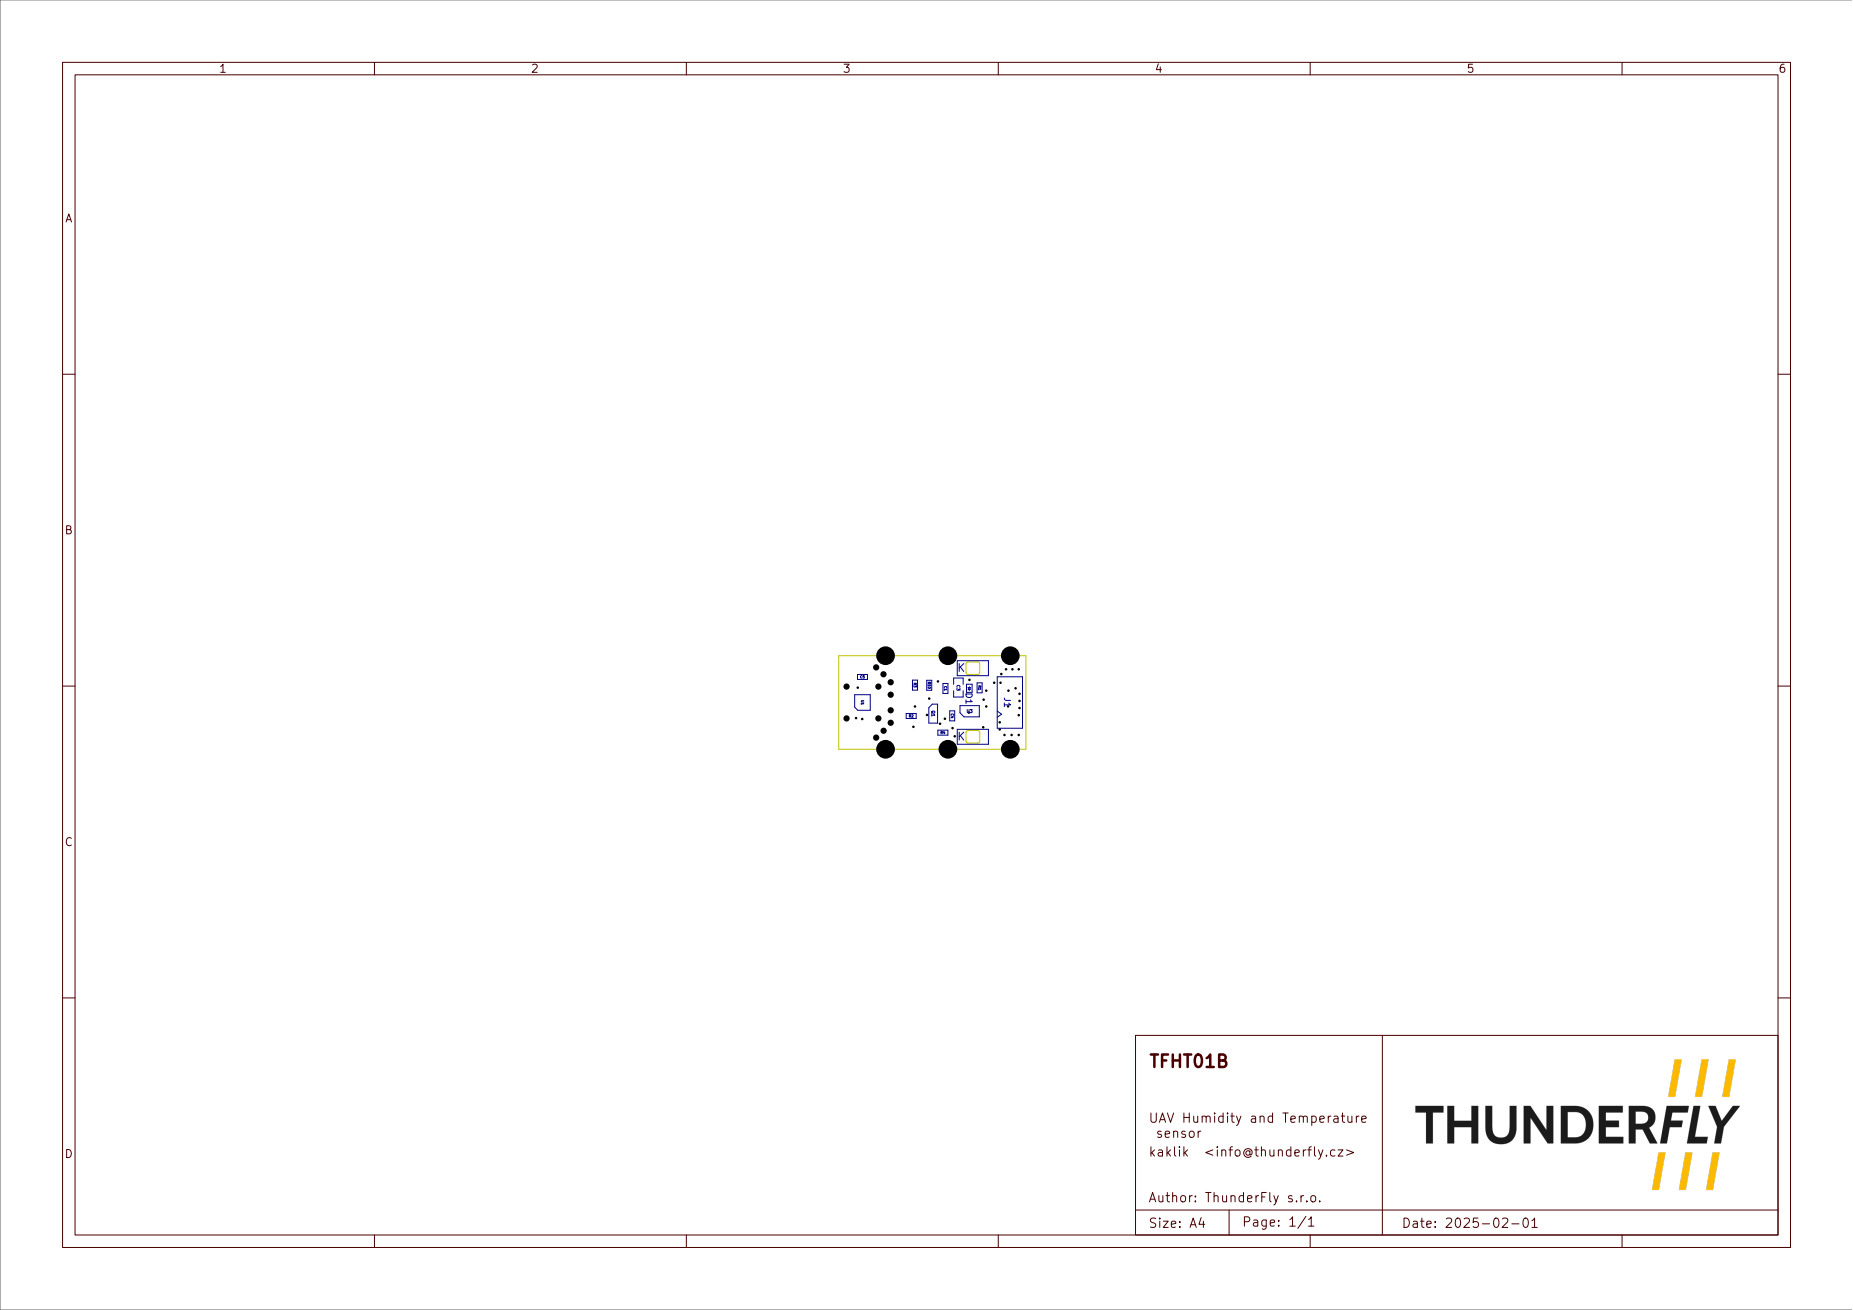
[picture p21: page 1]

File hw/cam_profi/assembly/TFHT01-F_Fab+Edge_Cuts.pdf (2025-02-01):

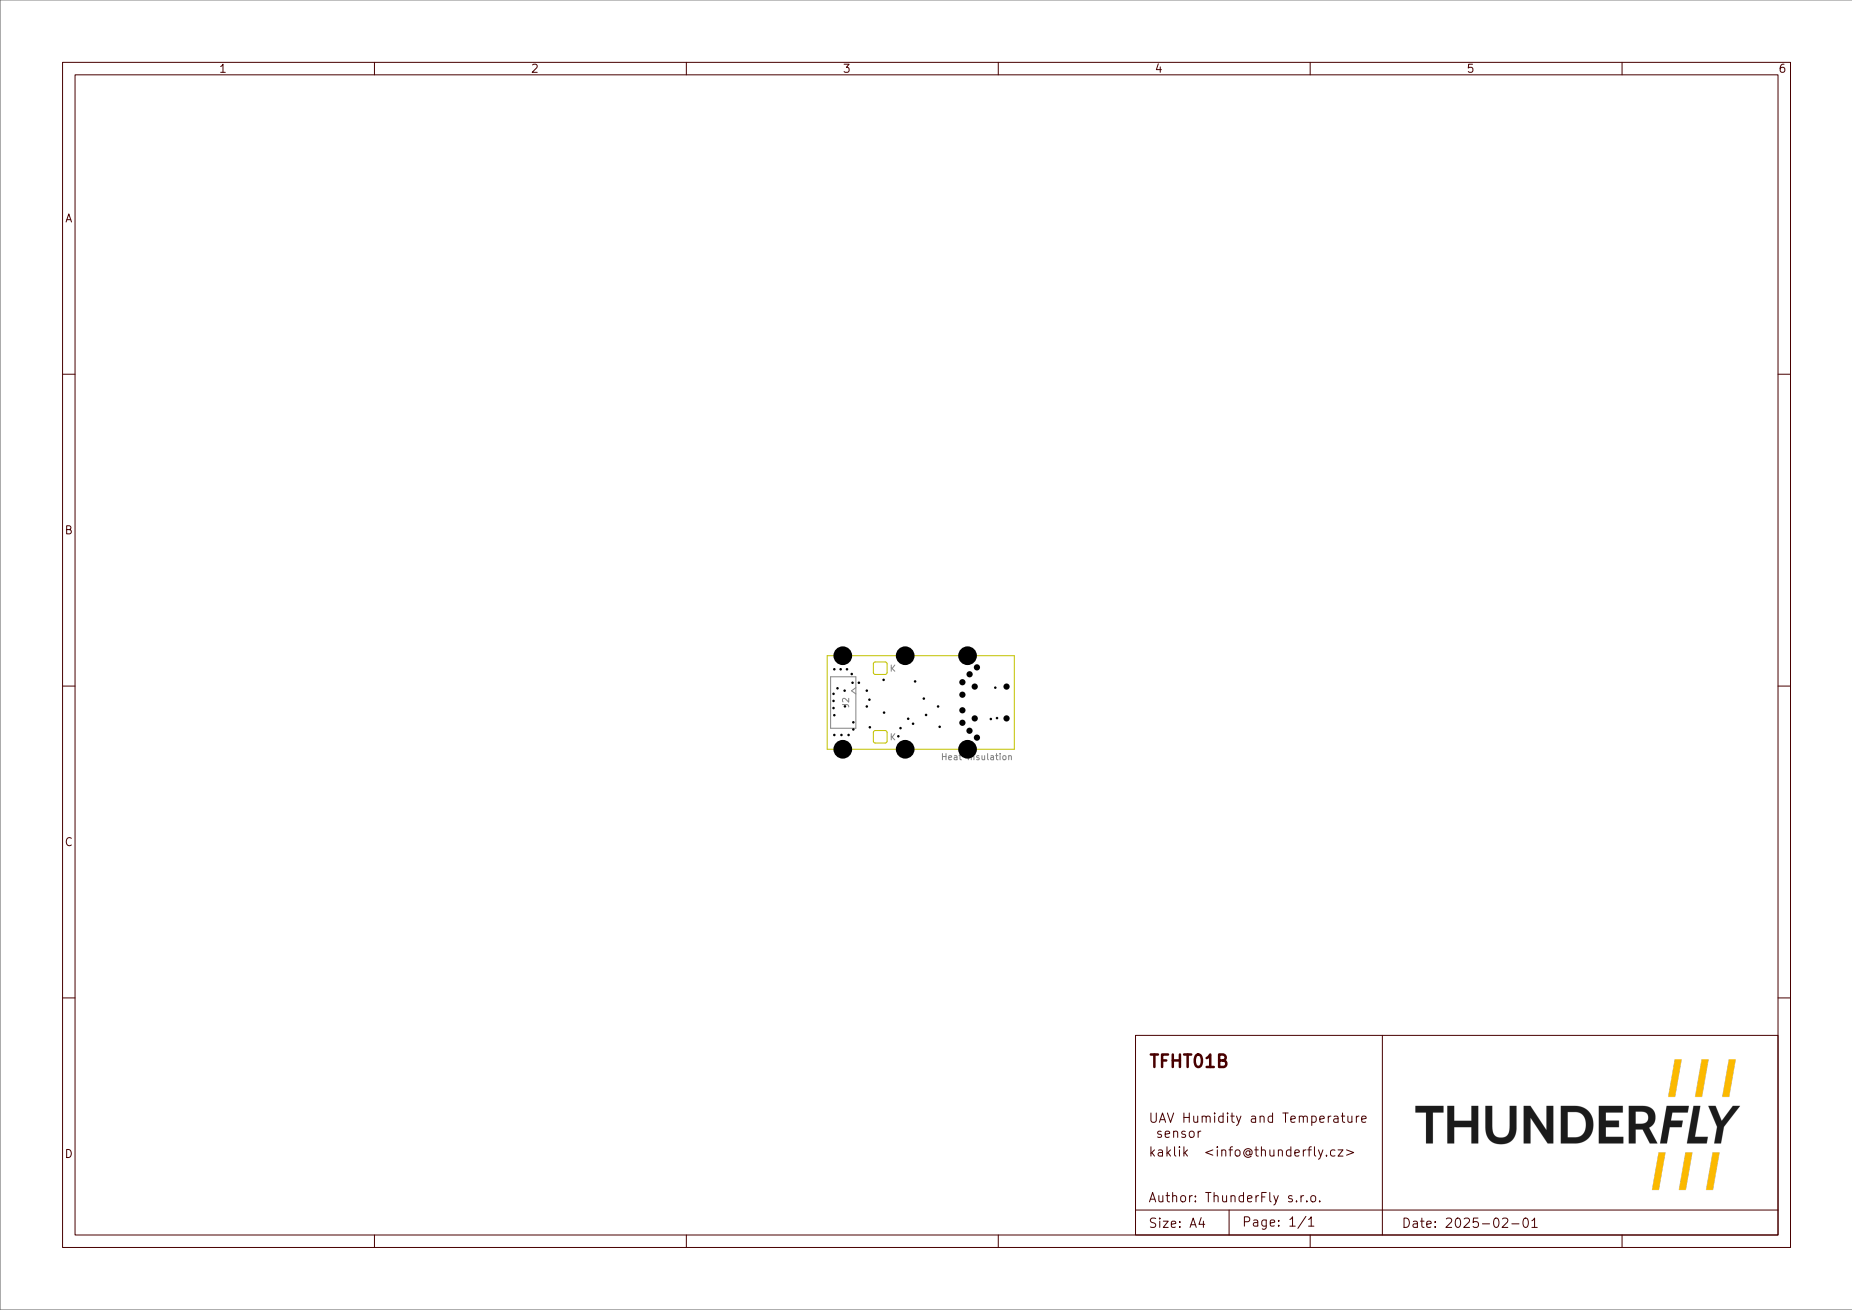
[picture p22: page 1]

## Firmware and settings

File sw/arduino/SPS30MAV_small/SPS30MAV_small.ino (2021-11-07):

#include "ArduinoMavlink.h"
#include <sps30.h>
/*

                     Mighty 1284p    
                      +---\/---+
           (D 0) PB0 1|        |40 PA0 (AI 0 / D24)
           (D 1) PB1 2|        |39 PA1 (AI 1 / D25)
      INT2 (D 2) PB2 3|        |38 PA2 (AI 2 / D26)
       PWM (D 3) PB3 4|        |37 PA3 (AI 3 / D27)
    PWM/SS (D 4) PB4 5|        |36 PA4 (AI 4 / D28)
      MOSI (D 5) PB5 6|        |35 PA5 (AI 5 / D29)
  PWM/MISO (D 6) PB6 7|        |34 PA6 (AI 6 / D30)
   PWM/SCK (D 7) PB7 8|        |33 PA7 (AI 7 / D31)
                 RST 9|        |32 AREF
                VCC 10|        |31 GND
                GND 11|        |30 AVCC
              XTAL2 12|        |29 PC7 (D 23)
              XTAL1 13|        |28 PC6 (D 22)
      RX0 (D 8) PD0 14|        |27 PC5 (D 21) TDI
      TX0 (D 9) PD1 15|        |26 PC4 (D 20) TDO
RX1/INT0 (D 10) PD2 16|        |25 PC3 (D 19) TMS
TX1/INT1 (D 11) PD3 17|        |24 PC2 (D 18) TCK
     PWM (D 12) PD4 18|        |23 PC1 (D 17) SDA
     PWM (D 13) PD5 19|        |22 PC0 (D 16) SCL
     PWM (D 14) PD6 20|        |21 PD7 (D 15) PWM
                      +--------+
*/

HardwareSerial &hs = Serial1;
ArduinoMavlink mav(hs);

#define PPS  12     // PD4
boolean led_status = false;
uint8_t data[42];

void setup() 
{
  int16_t ret;

  pinMode(PPS, INPUT);    // sets the digital pin as input

  Serial.begin(9600);
  Serial1.begin(57600);

  delay(250);
  while(!mav.begin())
  {
    Serial.println("Not Connected!");
    delay(250);
  }

  sensirion_i2c_init();

  while (sps30_probe() != 0) 
  {
    Serial.print("SPS sensor probing failed\n");
    delay(500);
  }
  Serial.print("SPS sensor probing successful\n");

  ret = sps30_start_measurement();
  if (ret < 0) 
  {
    Serial.print("error starting measurement\n");
  }
  Serial.print("measurements started\n");
  
  //mav.Stream();
  delay(2000);
}


void loop() 
{
  struct sps30_measurement m;
  char serial[SPS30_MAX_SERIAL_LEN];
  uint16_t data_ready;
  int16_t ret;

  while(digitalRead(PPS) == false);  // Waiting for 1PPS signal from GPS

  do 
  {
    ret = sps30_read_data_ready(&data_ready);
    if (ret < 0) 
    {
      Serial.print("error reading data-ready flag: ");
      Serial.println(ret);
    } 
    else if (!data_ready)
    {
      Serial.print("data not ready, no new measurement available\n");
      delay(100); /* retry in 100 ms */
    }
    else
      break;
  } while (1);
  
  ret = sps30_read_measurement(&m);
  if (ret < 0) {
    Serial.print("error reading measurement\n");
  } 
  else 
  {
    Serial.println();

    uint32_t MC1p0 = round(m.mc_1p0 * 100);
    uint32_t MC2p5 = round((m.mc_2p5 - m.mc_1p0) * 100);
    uint32_t MC4p0 = round((m.mc_4p0 - m.mc_2p5) * 100);
    uint32_t MC10p0 = round((m.mc_10p0 - m.mc_4p0) * 100);

    Serial.print("PM  0.3 - 1.0: ");
    Serial.println(m.mc_1p0);
    Serial.print("PM  1.0 - 2.5: ");
    Serial.println(m.mc_2p5 - m.mc_1p0);
    Serial.print("PM  2.5 - 4.0: ");
    Serial.println(m.mc_4p0 - m.mc_2p5);
    Serial.print("PM 4.0 - 10.0: ");
    Serial.println(m.mc_10p0 - m.mc_4p0);

    uint32_t NC0p5 = round(m.nc_0p5 * 100);
    uint32_t NC1p0 = round((m.nc_1p0 - m.nc_0p5) * 100);
    uint32_t NC2p5 = round((m.nc_2p5 - m.nc_1p0) * 100);
    uint32_t NC4p0 = round((m.nc_4p0 - m.nc_2p5) * 100);
    uint32_t NC10p0 = round((m.nc_10p0 - m.nc_4p0) * 100);
    
    mav.SendHeartBeat();

    Serial.print("NC  0.3 - 0.5:  ");
    Serial.println(m.nc_0p5);
    Serial.print("NC  0.5 - 1.0:  ");
    Serial.println(m.nc_1p0 - m.nc_0p5);
    Serial.print("NC  1.0 - 2.5:  ");
    Serial.println(m.nc_2p5 - m.nc_1p0);
    Serial.print("NC  2.5 - 4.0:  ");
    Serial.println(m.nc_4p0 - m.nc_2p5);
    Serial.print("NC  4.0 - 10.0: ");
    Serial.println(m.nc_10p0 - m.nc_4p0);

    uint32_t TPS = round(m.typical_particle_size * 100);
    
    Serial.print("Typical partical size: ");
    Serial.println(m.typical_particle_size);
  
    data[0] = (NC0p5) & 0xFF;
    data[1] = (NC0p5 >> 8) & 0xFF;
    data[2] = (NC0p5 >> 16) & 0xFF;
    data[3] = (NC0p5 >> 24) & 0xFF;
    data[4] = (NC1p0) & 0xFF;
    data[5] = (NC1p0 >> 8) & 0xFF;
    data[6] = (NC1p0 >> 16) & 0xFF;
    data[7] = (NC1p0 >> 24) & 0xFF;
    data[8] = (NC2p5) & 0xFF;
    data[9] = (NC2p5 >> 8) & 0xFF;
    data[10] = (NC2p5 >> 16) & 0xFF;
    data[11] = (NC2p5 >> 24) & 0xFF;
    data[12] = (NC4p0) & 0xFF;
    data[13] = (NC4p0 >> 8) & 0xFF;
    data[14] = (NC4p0 >> 16) & 0xFF;
    data[15] = (NC4p0 >> 24) & 0xFF;
    data[16] = (NC10p0) & 0xFF;
    data[17] = (NC10p0 >> 8) & 0xFF;
    data[18] = (NC10p0 >> 16) & 0xFF;
    data[19] = (NC10p0 >> 24) & 0xFF;
    data[20] = (MC1p0) & 0xFF;
    data[21] = (MC1p0 >> 8) & 0xFF;
    data[22] = (MC1p0 >> 16) & 0xFF;
    data[23] = (MC1p0 >> 24) & 0xFF;
    data[24] = (MC2p5) & 0xFF;
    data[25] = (MC2p5 >> 8) & 0xFF;
    data[26] = (MC2p5 >> 16) & 0xFF;
    data[27] = (MC2p5 >> 24) & 0xFF;
    data[28] = (MC4p0) & 0xFF;
    data[29] = (MC4p0 >> 8) & 0xFF;
    data[30] = (MC4p0 >> 16) & 0xFF;
    data[31] = (MC4p0 >> 24) & 0xFF;
    data[32] = (MC10p0) & 0xFF;
    data[33] = (MC10p0 >> 8) & 0xFF;
    data[34] = (MC10p0 >> 16) & 0xFF;
    data[35] = (MC10p0 >> 24) & 0xFF;
    data[36] = (TPS) & 0xFF;
    data[37] = (TPS >> 8) & 0xFF;
    data[38] = (TPS >> 16) & 0xFF;
    data[39] = (TPS >> 24) & 0xFF;
    data[40] = 255;
    data[41] = 255;

    // data array (max length 128), data array size, data type (0 default - unknown), target sysid, target compid
    // For unicast (only for logging purposes) set sysid and compid to match the autopilot. For realtime visualisation, you can
    // set sysid and comid to broadcast (0, 0)
    mav.SendTunnelData(data, sizeof(data), 0, 0, 0);
    
    led_status = !led_status;
    digitalWrite(13, led_status);
  }
  //delay(100);
}

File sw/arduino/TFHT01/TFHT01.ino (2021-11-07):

#include "ArduinoMavlink.h"
#include <HardwareSerial.h>
#include <SimpleTimer.h>
#include "Wire.h"
#include "SHT31.h"

#define SDAPIN  20
#define SCLPIN  21
#define RSTPIN  7

// SHT35 sensor(SCLPIN);
SHT31 sht;

SimpleTimer HbTim(1000);
SimpleTimer SensTim(500);

HardwareSerial &hs = Serial1;
ArduinoMavlink mav(hs);

const int LED1_PIN    = 1;
const int LED2_PIN    = 0;
int led1State = 0;
int led2State = 0;

uint8_t data[6]={0};

void setup() 
{

  
  Serial.begin(9600);
  Serial1.begin(57600);
  Wire.begin();
  Wire.setClock(100000);
  
  sht.begin(0x44, &Wire);    //Sensor I2C Address
  sht.heatOff();
  sht.reset();
  sht.clearStatus();
  Serial.print(sht.getError(), HEX);
  Serial.println();

  
  Serial.print(sht.getError(), HEX);
  Serial.println();
  

  Serial.println("Hello!");

  //while(!mav.begin())
  //{
  //  Serial.println("Not Connected!");
  //}

//  if(sensor.init())
//  {
//    Serial.println("sensor init failed!!!");
//  }
//  delay(100);

//  mav.Stream();

  pinMode(LED1_PIN, OUTPUT);
  pinMode(LED2_PIN, OUTPUT);
  digitalWrite(LED1_PIN, led1State);

  
  uint16_t stat = sht.readStatus();
  Serial.print(stat, BIN);
  Serial.println();

  
  Serial.print(sht.getError(), HEX);
  Serial.println();

    if (stat & SHT31_STATUS_HEATER_ON)
  {
    Serial.println("ON");
  } else {
    Serial.println("OFF");
  }

}


  uint16_t loop_c = 0;


void loop() 
{

    //Serial.println("loop");

   if (HbTim.isReady()) {
        mav.SendHeartBeat();
        
        led1State = !led1State;
        digitalWrite(LED1_PIN, led1State);
          
          // sht.heatOff();
//          sht.read();
//          Serial.print(sht.getTemperature());
//          Serial.print("\t");
//          Serial.println(sht.getHumidity());
//          sht.requestData();


        HbTim.reset();
   }


   if (SensTim.isReady()) {
        
        Serial.println("Sens loop");
        digitalWrite(LED2_PIN, 1);
        float temp,hum;
        sht.read();
        temp = sht.getTemperature();
        hum = sht.getHumidity();
        
        //led2State = !led2State;
        //digitalWrite(LED2_PIN, led2State);

        data[0] = (int) loop_c;
        data[1] = (int) temp;
        data[2] = (int) ((temp - (int)temp)*100);
        data[3] = (int) hum;
        data[4] = (int) ((hum - (int)hum)*100);
        
        mav.SendTunnelData(data, sizeof(data), 2, 1, 1);
        // 2 - datatype for TFHT01

        Serial.print("\t");
        Serial.print(temp);
        Serial.print("\t");
        Serial.print(hum);
        Serial.print("\n");

        loop_c += 1;
        SensTim.reset();
        digitalWrite(LED2_PIN, 0);
    }

}

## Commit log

2021-04-05 Edit schema
    [TFHT01A.kicad_pcb, TFHT01A.kicad_sch]
2021-04-05 Update schematics title block.
    [TFHT01A.kicad_sch]
2021-04-05 Schematic traces cleanup.
    [TFHT01A.kicad_sch]
2021-04-16 Edit PCB
    [TFHT01A.kicad_pcb, TFHT01A.kicad_sch]
2021-04-26 Minor graphics improvement.
    [TFHT01A.kicad_pcb, TFHT01A.kicad_sch]
2021-04-26 Generating production data
    [TFHT01A-B_Cu.gbr, TFHT01A-B_Mask.gbr, TFHT01A-B_Silkscreen.gbr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]
2021-09-01 temperature and huminity sensor code
2021-11-07 Update documentation.
    [TFHT01A.kicad_sch]
2022-03-12 Add filter cap SF2 option #5.
    [TFHT01A.kicad_pcb, TFHT01B.kicad_pcb, TFHT01B.kicad_sch]
2022-03-13 Shift sensor to the center of the cap.
    [TFHT01B.kicad_pcb]
2022-03-14 Update value of base resistor #7. Generate manufacturing outputs.
    [TFHT01A-B_Cu.gbr, TFHT01A-F_Cu.gbr, TFHT01A-F_Silkscreen.gbr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]
2022-03-14 Update title block. remove redundant orientation mark of U1.
    [TFHT01B.kicad_pcb, TFHT01B.kicad_sch]
2022-03-14 Add manufacturing code to U1.
    [TFHT01B.kicad_sch]
2022-03-14 Removing duplicite UST_id fields.
    [TFHT01B.kicad_sch]
2022-03-14 Change U1 footprint to KiCAD standard library footprint. The footprint respects Sensirion drawing from the datasheet.
    [TFHT01B.kicad_pcb, TFHT01B.kicad_sch]
2022-03-16 Push actions product
    [TFHT01B-B_Courtyard.dxf, TFHT01B-B_Cu.dxf, TFHT01B-B_Fab.dxf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]
2022-03-17 Move PCB to the center of the page. Regenerate component placement drawing.
    [TFHT01B.kicad_pcb]
2022-03-18 Exclude holes and solder jumper from bill of material.
    [TFHT01B.kicad_sch]
2022-03-18 Remove unecessary copper #7
    [TFHT01B.kicad_pcb, TFHT01B.kicad_sch]
2022-03-18 Change DRC and ERC setup.
    [TFHT01B.kicad_pcb, TFHT01B.kicad_sch]
2022-03-18 Resolve ERC issues.
    [TFHT01B.kicad_sch]
2022-03-18 Resolve DRC errors.
    [TFHT01B.kicad_pcb]
2022-03-18 Improve DRC setup.
    [TFHT01B.kicad_pcb]
2022-03-19 Move grid origin to PCB coordinates origin (left bottom PCB corner)
    [TFHT01B.kicad_pcb]
2022-03-19 Fix some DRC issues.
    [TFHT01B.kicad_pcb]
2022-03-19 Improve heat insulation of sensor #7.
    [TFHT01B.kicad_pcb, TFHT01B.kicad_sch]
2022-03-29 Clean repository
    [TFHT01B-B_Courtyard.dxf, TFHT01B-B_Cu.dxf, TFHT01B-B_Fab.dxf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]
2022-03-30 Update actions products
    [TFHT01B-B_Cu.gbr, TFHT01B-B_Mask.gbr, TFHT01B-B_Silkscreen.gbr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]
2023-09-24 Kontrola a upravy pred vyrobou
    [TFHT01B.kicad_pcb, TFHT01B.kicad_sch]
2023-09-24 Aktualizace kicad_outputs.yml
2023-09-24 Prejmenovani kicad projektu
    [TFHT01.kicad_pcb, TFHT01.kicad_sch]
2023-09-24 Uprava PCB a kontrola pred vyrobou
    [TFHT01.kicad_pcb, TFHT01.kicad_sch]
2023-09-24 Edit UST_ID
    [TFHT01.kicad_sch]
2023-10-02 Edit ID
    [TFHT01.kicad_sch]
2023-10-04 Edit B.Fab
    [TFHT01.kicad_pcb]
2023-10-17 Update README.md
    Add examples of PX4 driver usage.
2023-11-10 Update README.md
    Improve driver information.
2025-02-01 Update project to KiCADv8.
    [TFHT01.kicad_sch]
